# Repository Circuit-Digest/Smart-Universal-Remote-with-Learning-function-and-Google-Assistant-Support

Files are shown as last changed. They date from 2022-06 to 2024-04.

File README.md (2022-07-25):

# [Smart-Universal-Remote-with-Learning-function-and-Google-Assistant-Support](https://circuitdigest.com/microcontroller-projects/diy-smart-universal-ir-remote-controle)
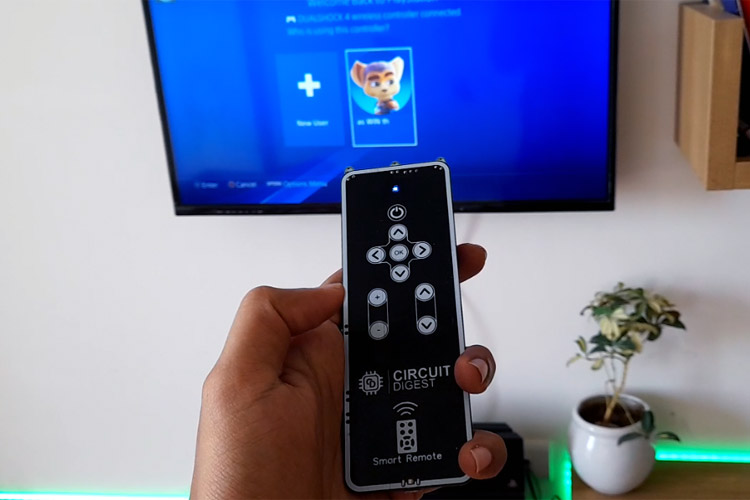
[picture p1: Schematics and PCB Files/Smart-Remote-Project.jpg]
image_tooltip

<br>

<br>

<br>

[<h1>Click here](https://circuitdigest.com/tags/ESP32) For other ESP32 tutorials.</h1>

<br>
<br>
In our day-to-day life, we use various gadgets such as television, set-top boxes, air conditioners, home theatre, DVD players, and many other remote-operated devices. Different gadgets means maintaining different remote controls which are not only clumsy but also difficult to manage. Universal remote control simplifies our life because it helps us control any IR devices in our daily life. So in this project we are going to build a single IR-based universal remote which can control all available IR-remote controlled electronic gadgets. 

<br>
[Note: As this projects are very simple we are only providing the code, schemaitic, and a few essential images if you want to get the images or code explanations do check out the Circuit Digest website.
<br>
<br>

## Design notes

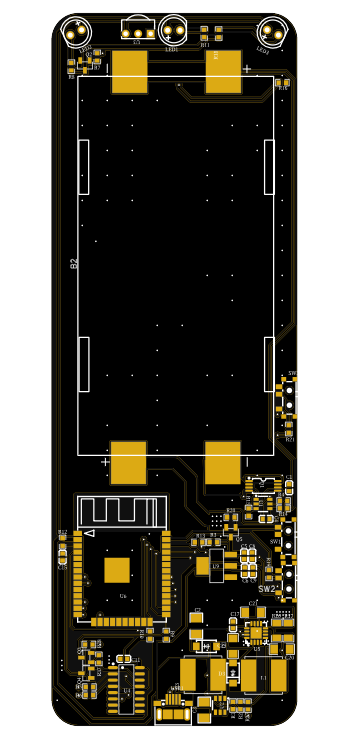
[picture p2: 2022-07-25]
Schematics and PCB Files/Screenshot 2022-06-07 180409.png

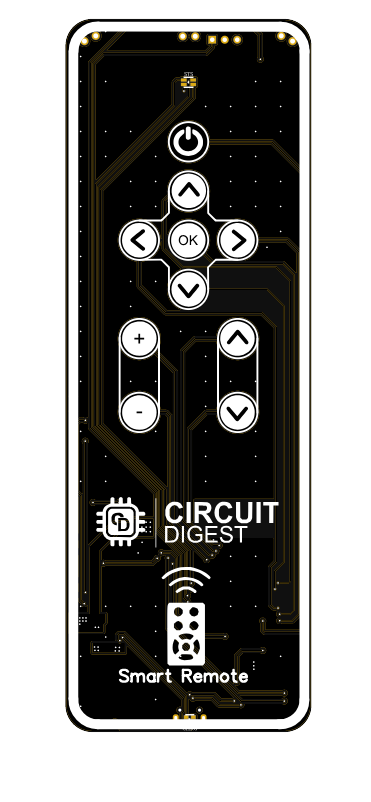
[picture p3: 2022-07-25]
Schematics and PCB Files/Screenshot 2022-06-07 180443.png

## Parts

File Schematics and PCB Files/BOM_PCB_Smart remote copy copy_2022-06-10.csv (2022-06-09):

ID | Name | Designator | Footprint | Quantity | Manufacturer Part | Manufacturer | Supplier | Supplier Part | Price
1 | TZ-P4-1615RGBTCA1-0.55T | CHRG | LED-SMD_4P-L1.6-W1.5-BR_TZ-P4-1615 | 1 | TZ-P4-1615RGBTCA1-0.55T | TUOZHAN | LCSC | C779813 | 0.024
2 | Touchpad | T4,T1,T2,T3,T5,T6,T7,T8,T9,T10 | TOUCH_D1 | 10 | New SchematicLib
3 | Li-ion 18650 SMD 1s2p | B2 | LI-ION 18650 DUAL SMD | 1 | BS-2-1 | Q&J | LCSC | C70376 | 0.079
4 | 0.1u | C1,C4,C17 | C0603 | 3
5 | 22uF | C2,C3 | 1206 | 2 | GRM31CR61E226KE15L | MuRata | LCSC | C77091 | 0.126
6 | 100nF | C8,C9 | C0603 | 2
7 | 1n | C15 | C0603 | 1
8 | 100nF | C11 | C0603 | 1 | CL05B104KO5NNNC | SAMSUNG | LCSC | C1525 | 0.001
9 | 10UF | C19,C20,C21 | C1206 | 3
10 | SS34 | D1 | SMA(DO-214AC) | 1 | SS34 | MDD | LCSC | C8678 | 0.048
11 | SS34 | D3 | SMA(DO-214AC) | 1 | SS34 | MDD | LCSC | C13763 | 0.072
12 | 22uH | L1,L3 | IND-SMD_L7.0-W6.8 | 2 | SMRH74-220MT | SXN | LCSC | C27442 | 0.178
13 | MHL5013UBDWT | LED1,LED2,LED3 | LED-TH_BD5.0-P2.54-L-RD_WHITE | 3 | MHL5013UBDWT | MEIHUA | LCSC | C559114 | 0.056
14 | 8205A | Q1 | TSSOP-8_L4.4-W3.0-P0.65-LS6.4-BL | 1 | 8205A | Hottech | LCSC | C181100 | 0.074
15 | S8050 | Q2,Q3,Q4 | SOT-23-3_L2.9-W1.3-P1.90-LS2.4-BR | 3 | S8050M-D | BLUE ROCKET | LCSC | C305482 | 0.013
16 | 1.2KΩ | R1 | R0603_NEW | 1 | 0805W8J0222T5E | UniOhm | LCSC | C26017 | 0.002
17 | 470 | R5,R6 | R0603_NEW | 2 | 0603WAF4700T5E | UniOhm | LCSC | C23179 | 0.001
18 | 4.7K | R9,R10 | R0603_NEW | 2
19 | 10k | R12,R19,R21 | R0603_NEW | 3
20 | 10K | R37,R38,R20 | R0603_NEW | 3 | 0603WAF1002T5E | UniOhm | LCSC | C25804 | 0.001
21 | 22k | R2 | R0603 | 1
22 | 100k | R3 | R0603 | 1
23 | 330 | R4,R14 | R0603 | 2
24 | 680 | R7 | R0603 | 1
25 | 1k | R8,R11,R16,R18 | R0603 | 4
26 | 47k | R13 | R0603 | 1
27 | 2k | R15 | R0603 | 1
28 | 100R | R17,R26 | R1206 | 2
29 | 1k | R27 | R0603_NEW | 1
30 | HY2120CB | U1 | SOT-23-6_L2.9-W1.6-P0.95-LS2.8-BR | 1 | HY2120CB | HYCON | LCSC | C116509 | 0.274
31 | MT3608 | U2 | SOT-23-6_L2.9-W1.6-P0.95-LS2.8-BR | 1 | MT3608 | AEROSEMI | LCSC | C84817 | 0.325
32 | VS1838B | U3 | OPTO-TH_VS1838B | 1 | VS1838B | null | LCSC | C9900002107
33 | CH340G | U4 | SOIC-16_L9.9-W3.9-P1.27-LS6.0-BL | 1 | CH340G | WCH | LCSC | C14267 | 0.462
34 | TP5100 | U5 | QFN-16_L4.0-W4.0-P0.65-BL-EP2.2 | 1 | TP5100 | TOPPOWER | LCSC | C29295
35 | ESP32-WROOM-32 | U6 | WIFIM-SMD_ESP-32S | 1 | ESP32-WROOM-32 | Espressif Systems | LCSC | C82899 | 3.846
36 | AMS1117-3.3 | U9 | SOT-223_L6.5-W3.5-P2.30-LS7.0-BR | 1 | AMS1117-3.3 | AMS | LCSC | C6186 | 0.146
37 | MICRO5.9MMUSB | USB1 | MICRO-USB-SMD_5P-P0.65-H-F_MICRO5.9MMUSB | 1 | MICRO5.9mmusb | SHOU HAN | LCSC | C393940 | 0.029
38 | 10u | C5,C6 | C0603 | 2
39 | K3-1296S-E2 | SW1,SW2,SW3 | SW-SMD_K3-1296S-E2 | 3 | K3-1296S-E2 | Rectangular Connectors - Contacts | LCSC | C136659 | 0.092
40 | AO3401 | Q5 | SOT-23-3_L2.9-W1.3-P1.90-LS2.4-BR | 1 | AO3401 | Hottech | LCSC | C181091 | 0.039
41 | TJ-S1615CY6TGLCCSRGB-A5 | STS | LED-ARRAY-SMD_4P-L1.6-W1.5-BL-FD | 1 | TJ-S1615CY6TGLCCSRGB-A5 | TOGIALED | LCSC | C601684 | 0.081

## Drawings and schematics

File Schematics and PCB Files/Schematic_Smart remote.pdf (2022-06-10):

## 2S Charger

Boost Converter | 2S Battery Protection

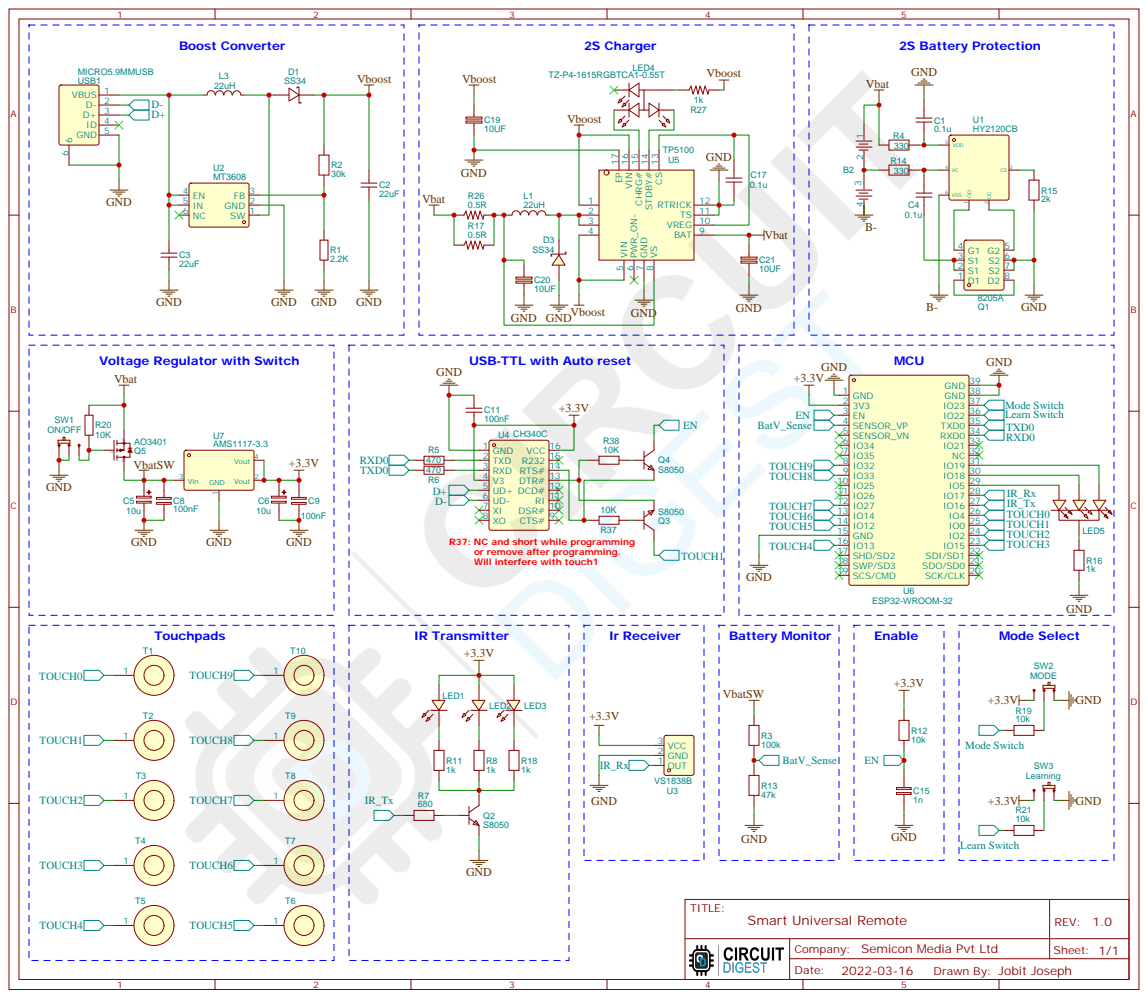
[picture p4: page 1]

VREG 10 TS 11 RTRICK 12 CS 13 STDBY# ¹⁴ CHRG# ¹⁵ VIN ¹⁶ EP 17

DSR# 10 RI 11 DCD# 12 DTR# 13 RTS# 14 R232 15 VCC 16

R37: NC and short while programming
or remove after programming.
Will interfere with touch1

Company: Semicon Media Pvt Ltd

Drawn By: Jobit Joseph

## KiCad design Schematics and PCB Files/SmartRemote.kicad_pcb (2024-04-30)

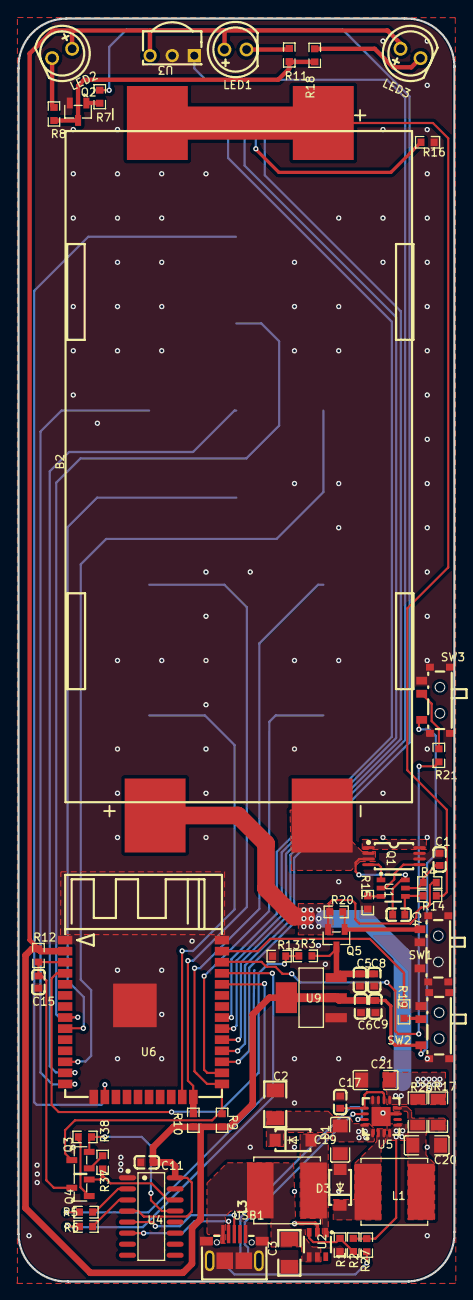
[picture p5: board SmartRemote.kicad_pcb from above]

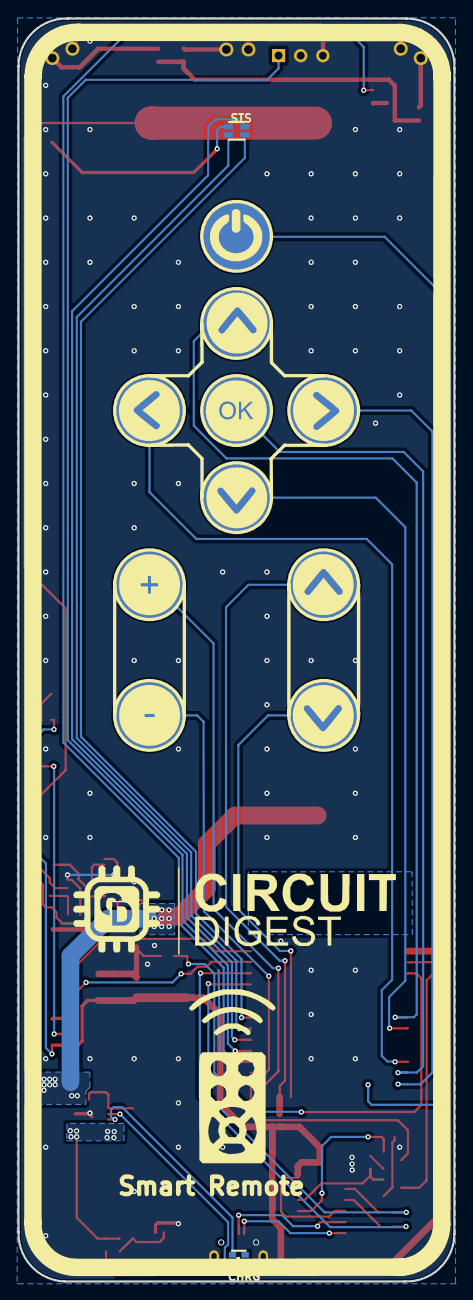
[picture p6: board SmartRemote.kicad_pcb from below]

Board: 2 copper layers, 50.0 x 145.0 mm, 75 parts (11 on the bottom side), 60 nets.

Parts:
B2: Li-ion 18650 SMD 1s2p; LI-ION 18650 DUAL SMD
C1, C4, C17: 0.1u; C0603
C2, C3: 22uF; 1206
C5, C6: 10u; C0603
C8, C9, C11: 100nF; C0603
C15: 1n; C0603
C19, C20, C21: 10UF; C1206
CHRG: TZ-P4-1615RGBTCA1-0.55T; LED-SMD_4P-L1.6-W1.5-BR_TZ-P4-1615
D1, D3: SS34; SMA(DO-214AC)
L1, L3: 22uH; IND-SMD_L7.0-W6.8
LED1, LED2, LED3: MHL5013UBDWT; LED-TH_BD5.0-P2.54-L-RD_WHITE
Q1: 8205A; TSSOP-8_L4.4-W3.0-P0.65-LS6.4-BL
Q2, Q3, Q4: S8050; SOT-23-3_L2.9-W1.3-P1.90-LS2.4-BR
Q5: AO3401; SOT-23-3_L2.9-W1.3-P1.90-LS2.4-BR
R1: 1.2KΩ; R0603_NEW
R2: 22k; R0603
R3: 100k; R0603
R4, R14: 330; R0603
R5, R6: 470; R0603_NEW
R7: 680; R0603
R8, R11, R16, R18: 1k; R0603
R9, R10: 4.7K; R0603_NEW
R12, R19, R21: 10k; R0603_NEW
R13: 47k; R0603
R15: 2k; R0603
R17, R26: 100R; R1206
R20, R37, R38: 10K; R0603_NEW
R27: 1k; R0603_NEW
STS: TJ-S1615CY6TGLCCSRGB-A5; LED-ARRAY-SMD_4P-L1.6-W1.5-BL-FD
SW1, SW2, SW3: K3-1296S-E2; SW-SMD_K3-1296S-E2
T1, T2, T3, T4, T5, T6, T7, T8, T9, T10: Touchpad; TOUCH_D1
U1: HY2120CB; SOT-23-6_L2.9-W1.6-P0.95-LS2.8-BR
U2: MT3608; SOT-23-6_L2.9-W1.6-P0.95-LS2.8-BR
U3: VS1838B; OPTO-TH_VS1838B
U4: CH340G; SOIC-16_L9.9-W3.9-P1.27-LS6.0-BL
U5: TP5100; QFN-16_L4.0-W4.0-P0.65-BL-EP2.2
U6: ESP32-WROOM-32; WIFIM-SMD_ESP-32S
U9: AMS1117-3.3; SOT-223_L6.5-W3.5-P2.30-LS7.0-BR
USB1: MICRO5.9MMUSB; MICRO-USB-SMD_5P-P0.65-H-F_MICRO5.9MMUSB

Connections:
+3.3V: C6.1, C9.2, C11.2, LED1.2, LED2.2, LED3.2, R9.2, R10.2, R12.2, SW2.1, SW3.1, U3.3, U4.4, U4.16, U6.2, U9.2, U9.4
B-: B2.4, C4.1, Q1.2, Q1.3, U1.6
BATV_SENSE: R3.1, R13.2, U6.4
C17_2: C17.2, U5.10, U5.13
D+: U4.5, USB1.3
D-: U4.6, USB1.2
EN: C15.2, Q4.3, R12.1, U6.3
GND: C1.2, C2.1, C3.1, C5.2, C6.2, C8.1, C9.1, C11.1, C15.1, C17.1, C19.2, C20.2, C21.2, D3.1, Q1.6, Q1.7, Q2.2, R1.1, R13.1, R15.1, R16.1, SW1.1, SW1.2, SW1.4, SW1.5, SW1.6, SW1.7, SW2.3, SW2.4, SW2.5, SW2.6, SW2.7, SW3.3, SW3.4, SW3.5, SW3.6, SW3.7, U2.2, U3.2, U4.1, U5.7, U5.11, U5.12, U5.17, U6.1, U6.15, U6.38, U6.39, U9.1, USB1.5, USB1.6
IR_RX: U3.1, U6.28
IR_TX: R7.1, U6.27
L1_1: C20.1, L1.1, R17.2, R26.2, U5.8
L1_2: D3.2, L1.2, U5.2, U5.3
L3_1: C3.2, L3.1, U2.4, U2.5, USB1.1
L3_2: D1.1, L3.2, U2.1
LEARNSWITCH: R21.2, U6.36
LED1_1: LED1.1, R11.2
LED2_1: LED2.1, R8.2
LED3_1: LED3.1, R18.2
LED4_1: CHRG.1, U5.14
LED4_2: CHRG.2, U5.15
MODESWITCH: R19.2, U6.37
Q1_1: Q1.1, Q1.8
Q2_1: Q2.1, R7.2
Q2_3: Q2.3, R8.1, R11.1, R18.1
Q3_1: Q3.1, R37.2
Q3_2: Q3.2, R38.1, U4.13
Q4_1: Q4.1, R38.2
Q4_2: Q4.2, R37.1, U4.14
R1_2: R1.2, R2.1, U2.3
R4_2: C1.1, R4.2, U1.5
R5_2: R5.2, U4.2
R6_2: R6.2, U4.3
R14_1: B2.2, B2.3, R14.1
R14_2: C4.2, R14.2, U1.4
R15_2: R15.2, U1.3
R16_2: R16.2, STS.4
R19_1: R19.1, SW2.2
R27_1: CHRG.4, R27.1
RXD0: R5.1, U6.34
SW1_3: Q5.1, R20.1, SW1.3
SW3_2: R21.1, SW3.2
TOUCH0: T1.1, U6.26
TOUCH1: Q3.3, R9.1, T2.1, U6.25
TOUCH2: R10.1, T3.1, U6.24
TOUCH3: T4.1, U6.23
TOUCH4: T5.1, U6.16
TOUCH5: T6.1, U6.14
TOUCH6: T7.1, U6.13
TOUCH7: T8.1, U6.12
TOUCH8: T9.1, U6.9
TOUCH9: T10.1, U6.8
TXD0: R6.1, U6.35
U1_1: Q1.4, U1.1
U1_2: Q1.5, U1.2
U6_29: STS.3, U6.29
U6_30: STS.1, U6.30
U6_31: STS.2, U6.31
VBAT: B2.1, C21.1, Q5.2, R4.1, R17.1, R20.2, R26.1, U5.9
VBATSW: C5.1, C8.2, Q5.3, R3.2, U9.3
VBOOST: C2.2, C19.1, D1.2, R2.2, R27.2, U5.1, U5.4, U5.5, U5.16

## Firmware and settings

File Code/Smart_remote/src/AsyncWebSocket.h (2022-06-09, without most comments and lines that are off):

#define ASYNCWEBSOCKET_H_
#include <Arduino.h>
#ifdef ESP32
#include "AsyncTCP.h"
#define WS_MAX_QUEUED_MESSAGES 32
#endif
#include "ESPAsyncWebServer.h"
#include "AsyncWebSynchronization.h"
#ifdef ESP8266
#include <Hash.h>
#ifdef CRYPTO_HASH_h // include Hash.h from espressif framework if the first include was from the crypto library
#include <../src/Hash.h>
#endif
#endif
#ifdef ESP32
#define DEFAULT_MAX_WS_CLIENTS 8
#else
#define DEFAULT_MAX_WS_CLIENTS 4
#endif
class AsyncWebSocket;
class AsyncWebSocketResponse;
class AsyncWebSocketClient;
class AsyncWebSocketControl;
typedef struct {
    uint8_t message_opcode;
    uint32_t num;
    uint8_t final;
    uint8_t masked;
    uint8_t opcode;
    uint64_t len;
    uint8_t mask[4];
    uint64_t index;
} AwsFrameInfo;
typedef enum { WS_DISCONNECTED, WS_CONNECTED, WS_DISCONNECTING } AwsClientStatus;
typedef enum { WS_CONTINUATION, WS_TEXT, WS_BINARY, WS_DISCONNECT = 0x08, WS_PING, WS_PONG } AwsFrameType;
typedef enum { WS_MSG_SENDING, WS_MSG_SENT, WS_MSG_ERROR } AwsMessageStatus;
typedef enum { WS_EVT_CONNECT, WS_EVT_DISCONNECT, WS_EVT_PONG, WS_EVT_ERROR, WS_EVT_DATA } AwsEventType;
class AsyncWebSocketMessageBuffer {
  private:
    uint8_t * _data;
    size_t _len;
    bool _lock;
    uint32_t _count;
  public:
    AsyncWebSocketMessageBuffer();
    AsyncWebSocketMessageBuffer(size_t size);
    AsyncWebSocketMessageBuffer(uint8_t * data, size_t size);
    AsyncWebSocketMessageBuffer(const AsyncWebSocketMessageBuffer &);
    AsyncWebSocketMessageBuffer(AsyncWebSocketMessageBuffer &&);
    ~AsyncWebSocketMessageBuffer();
    void operator ++(int i) { (void)i; _count++; }
    void operator --(int i) { (void)i; if (_count > 0) { _count--; } ;  }
    bool reserve(size_t size);
    void lock() { _lock = true; }
    void unlock() { _lock = false; }
    uint8_t * get() { return _data; }
    size_t length() { return _len; }
    uint32_t count() { return _count; }
    bool canDelete() { return (!_count && !_lock); }
    friend AsyncWebSocket;
};
class AsyncWebSocketMessage {
  protected:
    uint8_t _opcode;
    bool _mask;
    AwsMessageStatus _status;
  public:
    AsyncWebSocketMessage():_opcode(WS_TEXT),_mask(false),_status(WS_MSG_ERROR){}
    virtual ~AsyncWebSocketMessage(){}
    virtual void ack(size_t len __attribute__((unused)), uint32_t time __attribute__((unused))){}
    virtual size_t send(AsyncClient *client __attribute__((unused))){ return 0; }
    virtual bool finished(){ return _status != WS_MSG_SENDING; }
    virtual bool betweenFrames() const { return false; }
};
class AsyncWebSocketBasicMessage: public AsyncWebSocketMessage {
  private:
    size_t _len;
    size_t _sent;
    size_t _ack;
    size_t _acked;
    uint8_t * _data;
public:
    AsyncWebSocketBasicMessage(const char * data, size_t len, uint8_t opcode=WS_TEXT, bool mask=false);
    AsyncWebSocketBasicMessage(uint8_t opcode=WS_TEXT, bool mask=false);
    virtual ~AsyncWebSocketBasicMessage() override;
    virtual bool betweenFrames() const override { return _acked == _ack; }
    virtual void ack(size_t len, uint32_t time) override ;
    virtual size_t send(AsyncClient *client) override ;
};
class AsyncWebSocketMultiMessage: public AsyncWebSocketMessage {
  private:
    uint8_t * _data;
    size_t _len;
    size_t _sent;
    size_t _ack;
    size_t _acked;
    AsyncWebSocketMessageBuffer * _WSbuffer;
public:
    AsyncWebSocketMultiMessage(AsyncWebSocketMessageBuffer * buffer, uint8_t opcode=WS_TEXT, bool mask=false);
    virtual ~AsyncWebSocketMultiMessage() override;
    virtual bool betweenFrames() const override { return _acked == _ack; }
    virtual void ack(size_t len, uint32_t time) override ;
    virtual size_t send(AsyncClient *client) override ;
};
class AsyncWebSocketClient {
  private:
    AsyncClient *_client;
    AsyncWebSocket *_server;
    uint32_t _clientId;
    AwsClientStatus _status;
    LinkedList<AsyncWebSocketControl *> _controlQueue;
    LinkedList<AsyncWebSocketMessage *> _messageQueue;
    uint8_t _pstate;
    AwsFrameInfo _pinfo;
    uint32_t _lastMessageTime;
    uint32_t _keepAlivePeriod;
    void _queueMessage(AsyncWebSocketMessage *dataMessage);
    void _queueControl(AsyncWebSocketControl *controlMessage);
    void _runQueue();
  public:
    void *_tempObject;
    AsyncWebSocketClient(AsyncWebServerRequest *request, AsyncWebSocket *server);
    ~AsyncWebSocketClient();
    uint32_t id(){ return _clientId; }
    AwsClientStatus status(){ return _status; }
    AsyncClient* client(){ return _client; }
    AsyncWebSocket *server(){ return _server; }
    AwsFrameInfo const &pinfo() const { return _pinfo; }
    IPAddress remoteIP();
    uint16_t  remotePort();
    void close(uint16_t code=0, const char * message=NULL);
    void ping(uint8_t *data=NULL, size_t len=0);
    void keepAlivePeriod(uint16_t seconds){
      _keepAlivePeriod = seconds * 1000;
    }
    uint16_t keepAlivePeriod(){
      return (uint16_t)(_keepAlivePeriod / 1000);
    }
    void message(AsyncWebSocketMessage *message){ _queueMessage(message); }
    bool queueIsFull();
    size_t printf(const char *format, ...)  __attribute__ ((format (printf, 2, 3)));
#ifndef ESP32
    size_t printf_P(PGM_P formatP, ...)  __attribute__ ((format (printf, 2, 3)));
#endif
    void text(const char * message, size_t len);
    void text(const char * message);
    void text(uint8_t * message, size_t len);
    void text(char * message);
    void text(const String &message);
    void text(const __FlashStringHelper *data);
    void text(AsyncWebSocketMessageBuffer *buffer);
    void binary(const char * message, size_t len);
    void binary(const char * message);
    void binary(uint8_t * message, size_t len);
    void binary(char * message);
    void binary(const String &message);
    void binary(const __FlashStringHelper *data, size_t len);
    void binary(AsyncWebSocketMessageBuffer *buffer);
    bool canSend() { return _messageQueue.length() < WS_MAX_QUEUED_MESSAGES; }
    void _onAck(size_t len, uint32_t time);
    void _onError(int8_t);
    void _onPoll();
    void _onTimeout(uint32_t time);
    void _onDisconnect();
    void _onData(void *pbuf, size_t plen);
};
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

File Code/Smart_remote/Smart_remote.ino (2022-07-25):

/*****************************************************************************************************
 * Poject      : Smart Universal Remote
 * Description : Smart Universal Remote with Learning function and Google Assistant Support
 * Author      : Jobit Joseph
 * For         : CircuitDigest
 * Date        : 10-06-2022
 * Copy right : © Jobit Joseph – Circuit Digest (Semicon Media Pvt Ltd)
 *****************************************************************************************************/
/*
   Connection pinout
   Pwr   -- Touch4 -- IO13
   Ok    -- touch  -- 6 io14
   up    -- touch9 -- io32
   down  -- touch8 -- i033
   left  -- touch5 -- io12
   right -- touch7 --  io27
   next  -- touch2 -- io2
   prev  -- touch3 -- io15
   plus  -- touch1 -- io0
   minus -- touch0 -- io4
   Mode  -- switch -- IO23
   Learn -- Switch -- IO22
*/
#include <Arduino.h>
#include <WiFi.h>
#include <ESPmDNS.h>
#include "SPIFFS.h"
#include "PinDefinitionsAndMore.h" //Define macros for input and output pin etc.
#include "src/WiFiManager.h"
#include "src/AsyncElegantOTA.h"
#define RAW_BUFFER_LENGTH  750
#include "src/IRremote.hpp"
#include "src/AsyncTCP.h"
#include "src/ESPAsyncWebServer.h"
#define mode_switch 23
#define learn_switch 22
#include "src/Adafruit_MQTT.h"
#include "src/Adafruit_MQTT_Client.h"

/************************* Adafruit.io Setup *********************************/

#define AIO_SERVER      "io.adafruit.com"
#define AIO_SERVERPORT  1883                   // use 8883 for SSL
#define AIO_USERNAME    "jobitxxxxxxxx"            // Replace it with your Adafruit IO username
#define AIO_KEY         "aio_qOXrxxxxxxxxxxxxxxxxxxM4yyyi4"   // Replace with your Adafruit IO Project Auth Key

WiFiClient client;
// Setup the MQTT client class by passing in the WiFi client and MQTT server and login details.
Adafruit_MQTT_Client mqtt(&client, AIO_SERVER, AIO_SERVERPORT, AIO_USERNAME, AIO_KEY);

/****************************** Feeds ***************************************/


// Setup a feed called 'onoff' for subscribing to changes.
Adafruit_MQTT_Subscribe SRemote = Adafruit_MQTT_Subscribe(&mqtt, AIO_USERNAME"/feeds/smart-remote"); // FeedName




// Create AsyncWebServer object on port 80
AsyncWebServer server(80);
AsyncWebSocket ws("/ws");

int STATUS_PIN = 19;

int DELAY_BETWEEN_REPEAT = 50;
int DEFAULT_NUMBER_OF_REPEATS_TO_SEND = 3;

/* Html page for the websever*/
const char index_html[] PROGMEM = R"rawliteral(
<!DOCTYPE html>
<html>
<head>
  <link rel="icon" type="image/png" href="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
void loop() {
  modereset();
  if (SRmode == 0)
  {
    if (IrReceiver.available()) {
      storeCode(IrReceiver.read());
      IrReceiver.resume(); // resume receiver
    }
  }
  else
  {
    touch_detect();
    if (SRmode == 1)
    {
      MQTT_loop();
      /*Web client handling*/
      ws.cleanupClients();
    }
    else
    {
      /*In normal mode the remote will goto sleep after 20 Seconds. Adjust the sleep time by modifiying the value below*/
      if(millis()- lasttouch > 20000)
      {
      esp_sleep_enable_touchpad_wakeup();
      Serial.println("Going to sleep now");
      esp_deep_sleep_start();
      }
    }
  }

}

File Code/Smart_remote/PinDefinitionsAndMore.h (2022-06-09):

/*
 *  PinDefinitionsAndMore.h
 *
 *  Contains pin definitions for IRremote examples for various platforms
 *  as well as definitions for feedback LED and tone() and includes
 *
 *  Copyright (C) 2021-2022  Armin Joachimsmeyer
 *  armin.joachimsmeyer@gmail.com
 *
 *  This file is part of IRremote https://github.com/Arduino-IRremote/Arduino-IRremote.
 *
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
 */

/*
 * Pin mapping table for different platforms
 *
 * Platform     IR input    IR output   Tone      Core/Pin schema
 * --------------------------------------------------------------
 * DEFAULT/AVR  2           3           4
 * ATtinyX5     0|PB0       4|PB4       3|PB3
 * ATtiny167    3|PA3       2|PA2       7|PA7     ATTinyCore
 * ATtiny167    9|PA3       8|PA2       5|PA7     Digispark pro
 * ATtiny3217  18|PA1      19|PA2      20|PA3     MegaTinyCore
 * ATtiny1604   2           3|PA5       %
 * SAMD21       3           4           5
 * ESP8266      14|D5       12|D6       %
 * ESP32        15          4           27
 * BluePill     PA6         PA7         PA3
 * APOLLO3      11          12          5
 * RP2040       3|GPIO15    4|GPIO16    5|GPIO17
 */
//#define _IR_MEASURE_TIMING // For debugging purposes.

#if defined(ESP8266)
#define FEEDBACK_LED_IS_ACTIVE_LOW // The LED on my board (D4) is active LOW
#define IR_RECEIVE_PIN          14 // D5
#define IR_SEND_PIN             12 // D6 - D4/pin 2 is internal LED
#define _IR_TIMING_TEST_PIN     13 // D7
#define APPLICATION_PIN          0 // D3

#define tone(...) void()      // tone() inhibits receive timer
#define noTone(a) void()
#define TONE_PIN                42 // Dummy for examples using it

#elif defined(ESP32)
#include <Arduino.h>

// tone() is included in ESP32 core since 2.0.2
#if !defined(ESP_ARDUINO_VERSION_VAL)
#define ESP_ARDUINO_VERSION_VAL(major, minor, patch) 12345678
#endif
#if ESP_ARDUINO_VERSION  <= ESP_ARDUINO_VERSION_VAL(2, 0, 2)
#define TONE_LEDC_CHANNEL        1  // Using channel 1 makes tone() independent of receiving timer -> No need to stop receiving timer.
void tone(uint8_t aPinNumber, unsigned int aFrequency){
    ledcAttachPin(aPinNumber, TONE_LEDC_CHANNEL);
    ledcWriteTone(TONE_LEDC_CHANNEL, aFrequency);
}
void tone(uint8_t aPinNumber, unsigned int aFrequency, unsigned long aDuration){
    ledcAttachPin(aPinNumber, TONE_LEDC_CHANNEL);
    ledcWriteTone(TONE_LEDC_CHANNEL, aFrequency);
    delay(aDuration);
    ledcWriteTone(TONE_LEDC_CHANNEL, 0);
}
void noTone(uint8_t aPinNumber){
    ledcWriteTone(TONE_LEDC_CHANNEL, 0);
}
#endif // ESP_ARDUINO_VERSION  <= ESP_ARDUINO_VERSION_VAL(2, 0, 2)

#define IR_RECEIVE_PIN          17  // D15
#define IR_SEND_PIN              16  // D4
#define TONE_PIN                27  // D27 25 & 26 are DAC0 and 1
#define APPLICATION_PIN         21  // RX2 pin

#elif defined(ARDUINO_ARCH_STM32) || defined(ARDUINO_ARCH_STM32F1) // BluePill
// Timer 3 blocks PA6, PA7, PB0, PB1 for use by Servo or tone()
#define IR_RECEIVE_PIN          PA6
#define IR_SEND_PIN             PA7
#define TONE_PIN                PA3
#define _IR_TIMING_TEST_PIN     PA5
#define APPLICATION_PIN         PA2
#  if defined(ARDUINO_GENERIC_STM32F103C) || defined(ARDUINO_BLUEPILL_F103C8)
// BluePill LED is active low
#define FEEDBACK_LED_IS_ACTIVE_LOW
#  endif

#elif defined(__AVR_ATtiny25__) || defined(__AVR_ATtiny45__) || defined(__AVR_ATtiny85__) // Digispark board
#include "ATtinySerialOut.hpp" // Available as Arduino library "ATtinySerialOut". saves 370 bytes program memory and 38 bytes RAM for digistump core
#define IR_RECEIVE_PIN  0
#define IR_SEND_PIN     4 // Pin 2 is serial output with ATtinySerialOut. Pin 1 is internal LED and Pin3 is USB+ with pullup on Digispark board.
#define TONE_PIN        3
#define _IR_TIMING_TEST_PIN 3

#elif defined(__AVR_ATtiny87__) || defined(__AVR_ATtiny167__) // Digispark pro board
#include "ATtinySerialOut.hpp" // Available as Arduino library "ATtinySerialOut"
// For ATtiny167 Pins PB6 and PA3 are usable as interrupt source.
#  if defined(ARDUINO_AVR_DIGISPARKPRO)
#define IR_RECEIVE_PIN   9 // PA3 - on Digispark board labeled as pin 9
//#define IR_RECEIVE_PIN  14 // PB6 / INT0 is connected to USB+ on DigisparkPro boards
#define IR_SEND_PIN      8 // PA2 - on Digispark board labeled as pin 8
#define TONE_PIN         5 // PA7
#define _IR_TIMING_TEST_PIN 10 // PA4
#  else
#define IR_RECEIVE_PIN  3
#define IR_SEND_PIN     2
#define TONE_PIN        7
#  endif

#elif defined(__AVR_ATtiny88__) // MH-ET Tiny88 board
#include "ATtinySerialOut.hpp" // Available as Arduino library "ATtinySerialOut". Saves 128 bytes program memory
// Pin 6 is TX pin 7 is RX
#define IR_RECEIVE_PIN   3 // INT1
#define IR_SEND_PIN      4
#define TONE_PIN         9
#define _IR_TIMING_TEST_PIN 8
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

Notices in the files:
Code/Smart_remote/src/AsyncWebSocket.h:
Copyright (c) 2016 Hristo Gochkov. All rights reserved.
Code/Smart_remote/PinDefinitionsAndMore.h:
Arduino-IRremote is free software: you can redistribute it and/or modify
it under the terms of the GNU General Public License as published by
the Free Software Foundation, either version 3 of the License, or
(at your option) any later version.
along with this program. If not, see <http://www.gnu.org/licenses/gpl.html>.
